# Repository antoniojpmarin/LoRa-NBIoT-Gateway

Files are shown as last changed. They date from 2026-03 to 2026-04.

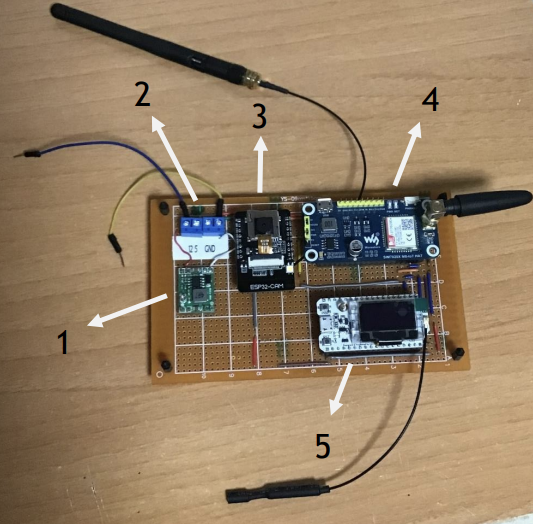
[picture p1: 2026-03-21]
hardware/tfg_image.png

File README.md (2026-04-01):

# Wireless Embedded System for Image Capture, Data Logging and Actuation

**Bachelor's Thesis (TFG)**  
Degree in Industrial Electronics and Automation Engineering  
Universidad Politécnica de Cartagena (UPCT) · July 2024

**Author:** Antonio Joaquín Piñera Marín

---

## Overview

Design and implementation of a low-power wireless embedded system for IoT environments. The system integrates a **LoRa Gateway with NB-IoT connectivity** and an **image capture node**, capable of collecting sensor data, transmitting it over LoRa, pushing it to a cloud IoT platform, and storing images remotely. The project was validated in a real outdoor deployment.

---

## System Architecture

```
[LoRa sensor node]
        │  LoRa (radio)
        ▼
[Gateway — Heltec WiFi LoRa32 (V2)]
   ├── NB-IoT (SIM7020-E) ──────► Thingspeak (sensor data)
   └── [ESP32-CAM] ─── WiFi ───► Firebase Storage (images)
```

The system operates autonomously powered by a solar panel and lead-acid battery.

---

## Hardware

[Perfboard Prototype](https://github.com/antoniojpmarin/LoRa-NBIoT-Gateway/blob/main/hardware/tfg_image.png)

| Component | Role | Number in Image |
|---|---|:---:|
| Heltec WiFi LoRa32 (V2) | Main MCU + LoRa radio + OLED display | 5 |
| ESP32-CAM + OV2640 | Image capture and upload (up to 2 MP) | 3 |
| SIM7020-E | NB-IoT connectivity (M2M) | 4 |
| Solar panel + Lead-acid battery | Autonomous outdoor power supply | Not in the Image |
| Buck converter MP1584 (DC-DC) | Voltage regulation | 1 |
| Perfboard | Final assembly and soldering | Image |

> **Note:** Number **2** in the image corresponds to the **Power Supply Input** (12 V input → 5 V after the DC‑DC converter, or direct 5 V input).

---

## Software

The firmware is split into two independent modules, both developed in **C/C++ with Arduino IDE 2.0**:

### `camera/`
ESP32-CAM node firmware. Handles:
- OV2640 camera module initialisation and configuration
- Periodic image capture
- Authentication and upload to **Firebase Storage** over WiFi
- Low-power modes (*deep sleep*)

### `gateway/`
Heltec WiFi LoRa32 (V2) Gateway firmware. Handles:
- LoRa frame reception from remote sensor nodes
- Data forwarding to **Thingspeak** via the NB-IoT SIM7020-E module (AT commands over UART)
- System status display on the OLED screen
- Coordination with the ESP32-CAM module

---

## Communication Protocols

- **LoRa / LoRaWAN** — long-range, low-power radio link between nodes and Gateway
- **NB-IoT** — cellular connectivity for cloud data upload (SIM7020-E via AT commands / UART)
- **WiFi** — image transfer from ESP32-CAM to Firebase
- **SPI** — interface with the LoRa radio module
- **I²C** — OLED display on the Heltec board
- **UART** — main MCU ↔ SIM7020-E communication

---

## Cloud Platforms

- **[Thingspeak](https://thingspeak.com)** — time-series storage and visualisation of sensor data
- **[Firebase Storage](https://firebase.google.com)** — image storage with authentication and real-time access

---

## Dependencies

Install the following libraries via Arduino IDE Library Manager before compiling:

| Library | Author | Used in |
|---|---|---|
| `LoRa` | Sandeep Mistry | `gateway/` |
| `Firebase ESP Client` | Mobizt | `camera/` |
| `LittleFS` | lorol | `camera/` |
| `esp_camera` | Espressif (built-in) | `camera/` |
| `HardwareSerial` | Espressif (built-in) | `gateway/` |

Board support: install **ESP32 by Espressif Systems** via Arduino IDE Boards Manager.

---

## Results

- Functional LoRa transmission between node and Gateway in an outdoor environment
- Image capture at up to **2 megapixels** with clear visual quality
- Sensor data available on Thingspeak in near real-time after reception
- Images stored on Firebase immediately after capture
- System validated in a real-world deployment (outdoor garden)

---

## Repository Structure

```
├── camera/           # ESP32-CAM firmware (C/C++)
├── gateway/          # LoRa + NB-IoT Gateway firmware (C/C++)
├── hardware/         # KiCad Schematics (MCU, power supply, Buck converter, SIM7020-E, CAM)
└── README.md
```

---

## Tech Stack

**MCU:** ESP32 ( Heltec WiFi LoRa32 V2, ESP32-CAM)  
**Protocols:** LoRa, NB-IoT, WiFi, SPI, I²C, UART  
**Cloud:** [Firebase](https://firebase.google.com/), [Thingspeak](https://thingspeak.mathworks.com/)  
**Languages:** C / C++  
**IDE:** Arduino IDE 2.0
**Schematics:** KiCad

---

## Future Work

- PCB design to reduce footprint, improve robustness and power efficiency
- Computer vision integration (intrusion detection, facial recognition)
- Mobile application development connected to Firebase
- End-to-end data encryption for improved security
- Unification of all communications into a single radio module (WiFi or M2M)

---

## License

Academic project — UPCT 2024. All rights reserved by the author.

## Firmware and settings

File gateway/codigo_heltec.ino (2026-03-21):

#include <SPI.h>
#include <LoRa.h>
#include <HardwareSerial.h>

String receivedData = "";

// Circular buffer size
const int tam_cir_buffer = 15;

// Pins
const int pwrsim7020 = 13;              // Power control pin for SIM7020E
const int pin_cam_signal_sleep = 36;    // Interrupt pin: CAM notifies it entered deep sleep
const int pin_pedir_foto = 23;          // Pin to wake the ESP32-CAM and request a picture

// States
bool flag_data = false;                 // True when a LoRa message has been received
bool cam_sleep = false;                 // True when CAM triggers sleep interrupt

// Deep sleep timing for the camera
long sleep_time = 1000 * 60 * 60;       // 1 hour
long t_inicio_sleep = 0;                // Timestamp of last wake-up

// Circular buffer to store last received values
int circularBuffer[tam_cir_buffer];
int pos_buffer = 0;

// Hardware serial for SIM7020E (UART2)
HardwareSerial sim7020(2);

// SIM7020E UART pins
#define SIM7020_RX_PIN 16
#define SIM7020_TX_PIN 17

// LoRa transceiver pins (SX1276)
#define SCK 5
#define MISO 19
#define MOSI 27
#define SS 18
#define RST 14
#define DIO0 26

void setup(){
  delay(1000);

  Serial.begin(115200);  
  sim7020.begin(115200, SERIAL_8N1, SIM7020_RX_PIN, SIM7020_TX_PIN); // Start SIM7020 UART

  // Configure pins
  pinMode(pwrsim7020, OUTPUT);
  pinMode(pin_pedir_foto, OUTPUT);
  pinMode(pin_cam_signal_sleep, INPUT);

  // Interrupt: CAM notifies when it enters deep sleep
  attachInterrupt(digitalPinToInterrupt(pin_cam_signal_sleep), cam_a_sleep, RISING);

  // Initialize SPI for LoRa
  SPI.begin(SCK, MISO, MOSI, SS);
  LoRa.setPins(SS, RST, DIO0);

  // Start LoRa at 868 MHz
  if (!LoRa.begin(868E6)) {
    Serial.println("Starting LoRa failed!");
    while (1);
  }
  Serial.println("LoRa system Initializing OK!");

  // Initialize circular buffer with -1 (invalid value)
  for (int i = 0; i < tam_cir_buffer; ++i) {
    circularBuffer[i] = -1;
  }

  // Set LoRa to receive mode
  Serial.println("Setting LoRa to receive mode");
  LoRa.onReceive(onReceive);
  LoRa.receive();
}

void loop(){

  // If a LoRa message was received
  if (flag_data){
    Serial.println("Message received!");
    power_on_sim7020();     // Turn on SIM7020E
    delay(800);
    flag_data = false;
    processReceivedData();  // Convert, store and upload the data
  }

  // Wake the CAM every hour to take a picture
  if (millis() - t_inicio_sleep > sleep_time){
    digitalWrite(pin_pedir_foto, HIGH);   // Wake-up pulse
    delay(350);
    digitalWrite(pin_pedir_foto, LOW);
    Serial.println("Waking up the CAM to take a picture!");
    t_inicio_sleep = millis();
  }

  // If CAM triggered sleep interrupt
  if (cam_sleep){
    Serial.println("The CAM has gone to sleep!");
    cam_sleep = false;
  }
}

/*
****************************************************************************************************************************************
  FUNCTION: Upload data to ThingSpeak using SIM7020E HTTP commands
****************************************************************************************************************************************
*/

void upload_data_thingspeak(int dato_){
  sendATCommand("AT");  // Basic check
  sendATCommand("AT+CHTTPCREATE=\"http://api.thingspeak.com/update.json\""); // Create HTTP session
  sendATCommand("AT+CHTTPCON=0"); // Connect session

  String dato_hex = int2hex(dato_);  // Convert number to ASCII HEX
  Serial.println("Received number in hex: " + dato_hex);

  // Send JSON payload encoded in HEX
  sendATCommand("AT+CHTTPSEND=0,1,\"/\",436f6e6e656374696f6e3a204b6565702d416c6976650a557365722d4167656e743a2053494d434f4d5f4d4f44554c450d0a,\"application/json\",7B226170695F6B6579223A222A222C226669656C6431223A"+ dato_hex +"7d");

  sendATCommand("AT+CHTTPDISCON=0");  // Disconnect
  sendATCommand("AT+CHTTPDESTROY=0"); // Destroy session
}

/*
****************************************************************************************************************************************
  FUNCTION: Update circular buffer index
****************************************************************************************************************************************
*/

void actualizar_pos_cir_buffer(){
  pos_buffer++;
  if (pos_buffer >= tam_cir_buffer)
    pos_buffer = 0;
}

/*
****************************************************************************************************************************************
  CALLBACK: Executed when a LoRa packet is received
****************************************************************************************************************************************
*/

void onReceive(int packetSize) {
  receivedData = "";

  // Read all bytes from LoRa buffer
  while (LoRa.available()) {
    receivedData += (char)LoRa.read();
  }

  flag_data = true;  // Notify main loop
}

/*
****************************************************************************************************************************************
  FUNCTION: Process received LoRa data
****************************************************************************************************************************************
*/

void processReceivedData(){
  int dato_int;
  String myString = "";

  // Copy received string
  for (char c : receivedData) {
    myString += c;
  }

  Serial.println("Received number: " + myString);

  // Convert to integer
  dato_int = myString.toInt();
  myString = "";

  // Store in circular buffer
  circularBuffer[pos_buffer] = dato_int;

  // Upload to ThingSpeak
  upload_data_thingspeak(dato_int);
  
  actualizar_pos_cir_buffer();  // Move buffer index
  power_off_sim7020();          // Turn off SIM7020E to save power
}

/*
****************************************************************************************************************************************
  FUNCTION: Send AT command to SIM7020E and wait for "OK"
****************************************************************************************************************************************
*/

void sendATCommand(String command) {
  delay(10);
  sim7020.println(command);  // Send command to SIM7020E

  int t = millis();
  int t_max = 10000;
  String response = "";

  // Wait for response or timeout
  while (millis() - t < t_max){
    delay(20);
    
    if (sim7020.available()) {
      char c = sim7020.read();
      response += c;
      delay(10);
    }

    if (response.indexOf("OK") != -1) {
      break;  // Stop when OK is received
    }
  }

  Serial.println(response);  // Print module response
}

/*
****************************************************************************************************************************************
  INTERRUPT: Called when CAM enters deep sleep
****************************************************************************************************************************************
*/

void cam_a_sleep(){
  cam_sleep = true;
  t_inicio_sleep = millis();  // Reset sleep timer
}

/*
****************************************************************************************************************************************
  FUNCTION: Power ON SIM7020E using pulse sequence
****************************************************************************************************************************************
*/

void power_on_sim7020(){
  digitalWrite(pwrsim7020, LOW);
  delay(100);
  digitalWrite(pwrsim7020, HIGH);
  Serial.println("Powering on SIM7020");
  delay(500);
  digitalWrite(pwrsim7020, LOW);
  delay(1000);
}

/*
****************************************************************************************************************************************
  FUNCTION: Power OFF SIM7020E using pulse sequence
****************************************************************************************************************************************
*/

void power_off_sim7020(){
  digitalWrite(pwrsim7020, LOW);
  delay(100);
  digitalWrite(pwrsim7020, HIGH);
  Serial.println("Powering off SIM7020");
  delay(1000);
  digitalWrite(pwrsim7020, LOW);
}

/*
****************************************************************************************************************************************
  FUNCTION: Convert integer to ASCII HEX for ThingSpeak
****************************************************************************************************************************************
*/

String int2hex(int n){
  String str = String(n);
  String str_valido = ""; // Must start with 3 (ASCII hex prefix)

  for (int i = 0; i < str.length(); i++) {
    if (str.charAt(i) == '.') {
      str_valido += "2e";  // ASCII hex for '.'
    } else {
      str_valido += 3;     // Prefix for ASCII hex digits
      str_valido += str.charAt(i);
    }
  }

  return str_valido;
}

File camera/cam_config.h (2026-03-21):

// OV2640 camera module pins (CAMERA_MODEL_AI_THINKER)
#define PWDN_GPIO_NUM     32
#define RESET_GPIO_NUM    -1
#define XCLK_GPIO_NUM      0
#define SIOD_GPIO_NUM     26
#define SIOC_GPIO_NUM     27
#define Y9_GPIO_NUM       35
#define Y8_GPIO_NUM       34
#define Y7_GPIO_NUM       39
#define Y6_GPIO_NUM       36
#define Y5_GPIO_NUM       21
#define Y4_GPIO_NUM       19
#define Y3_GPIO_NUM       18
#define Y2_GPIO_NUM        5
#define VSYNC_GPIO_NUM    25
#define HREF_GPIO_NUM     23
#define PCLK_GPIO_NUM     22


void initCamera(){
 // OV2640 camera module
  camera_config_t config;
  config.ledc_channel = LEDC_CHANNEL_0;
  config.ledc_timer = LEDC_TIMER_0;
  config.pin_d0 = Y2_GPIO_NUM;
  config.pin_d1 = Y3_GPIO_NUM;
  config.pin_d2 = Y4_GPIO_NUM;
  config.pin_d3 = Y5_GPIO_NUM;
  config.pin_d4 = Y6_GPIO_NUM;
  config.pin_d5 = Y7_GPIO_NUM;
  config.pin_d6 = Y8_GPIO_NUM;
  config.pin_d7 = Y9_GPIO_NUM;
  config.pin_xclk = XCLK_GPIO_NUM;
  config.pin_pclk = PCLK_GPIO_NUM;
  config.pin_vsync = VSYNC_GPIO_NUM;
  config.pin_href = HREF_GPIO_NUM;
  config.pin_sscb_sda = SIOD_GPIO_NUM;
  config.pin_sscb_scl = SIOC_GPIO_NUM;
  config.pin_pwdn = PWDN_GPIO_NUM;
  config.pin_reset = RESET_GPIO_NUM;
  config.xclk_freq_hz = 20000000;
  config.pixel_format = PIXFORMAT_JPEG;
  config.grab_mode = CAMERA_GRAB_LATEST;

  if (psramFound()) {
    config.frame_size = FRAMESIZE_UXGA;
    config.jpeg_quality = 10;
    config.fb_count = 1;
  } else {
    config.frame_size = FRAMESIZE_SVGA;
    config.jpeg_quality = 12;
    config.fb_count = 1;
  }
  // Camera init
  esp_err_t err = esp_camera_init(&config);
  if (err != ESP_OK) {
    Serial.printf("Camera init failed with error 0x%x", err);
    ESP.restart();
  } 
}

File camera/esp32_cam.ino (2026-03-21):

#include "WiFi.h"
#include "esp_camera.h"
#include "soc/soc.h"           // Disable brownout problems
#include "soc/rtc_cntl_reg.h"  // Disable brownout problems
#include "driver/rtc_io.h"
#include <LittleFS.h>
#include <Firebase_ESP_Client.h>
#include <addons/TokenHelper.h>
#include "esp_sleep.h"

#include "cam_config.h"
#include "firebase_datos.h"

const char* ssid = "******";
const char* password = "*******";

int intentos_subir_foto = 0, ledpin = 4, go_sleep = 12;
String filePath = "";
bool foto_subida = false;
bool debug = true;

void setup() {
  delay(500);

  if (debug){
    Serial.begin(115200);
  }

  pinMode(ledpin, OUTPUT);
  pinMode(go_sleep, OUTPUT);

  Serial.println("Hola");

  esp_sleep_enable_ext0_wakeup(GPIO_NUM_13, 1);

  if(!LittleFS.begin()){
    Serial.println("LittleFS Mount Failed");
  }

  LittleFS.format(); // Limpio LittleFS

  WRITE_PERI_REG(RTC_CNTL_BROWN_OUT_REG, 0);
  initCamera();
}

void loop(){
  // Toma una foto y guárdala
  capturePhotoSaveLittleFS();
  Serial.println(String("Nombre del archivo: ") + String("/data") + filePath);

  int n = 0;
  WiFi.begin(ssid, password);
  while (WiFi.status() != WL_CONNECTED && n < 15){
    n++;
    Serial.print("*");
    delay(1000);
  }
  Serial.println("");

  if (WiFi.status() == WL_CONNECTED){
    firebase();
  }

  while (intentos_subir_foto < 3 && !foto_subida && WiFi.status() == WL_CONNECTED){
    if (Firebase.Storage.upload(&fbdo, STORAGE_BUCKET_ID, filePath, mem_storage_type_flash, "/data"+filePath, "image/jpeg")){
      Serial.println("Foto Subida a Firebase!");
      foto_subida = true;
    }
    else intentos_subir_foto++;
  }

  if (intentos_subir_foto == 3 && !foto_subida){
    Serial.println("No se ha podido subir la foto!!!!");
  }

  Serial.println("Vamos al modo sleep!");

  digitalWrite(go_sleep, HIGH);
  delay(400);
  digitalWrite(go_sleep, LOW);

  digitalWrite(ledpin, HIGH);
  delay(300);
  digitalWrite(ledpin, LOW);
  delay(200);
  digitalWrite(ledpin, HIGH);
  delay(300);
  digitalWrite(ledpin, LOW);
  delay(200);
  digitalWrite(ledpin, HIGH);
  delay(300);
  digitalWrite(ledpin, LOW);
  delay(200);

  esp_deep_sleep_start();
}

//Firebase
void firebase(){
  // Api Key
  configF.api_key = API_KEY;

  // Credenciales de incio de sesión
  auth.user.email = USER_EMAIL;
  auth.user.password = USER_PASSWORD;

  // Función callback para el token de generación
  //configF.token_status_callback = tokenStatusCallback; //see addons/TokenHelper.h

  Firebase.begin(&configF, &auth);
  //Firebase.reconnectWiFi(true);
  Serial.println("Firebase configurado!");
}

// Capture Photo and Save it to LittleFS
void capturePhotoSaveLittleFS( void ) {
  // Descartar primeras imágenes debido a la mala calidad
  camera_fb_t *fb = NULL;
  // Omitir los primeros 3 fotogramas (aumentar o disminuir según sea necesario).

  for (int i = 0; i < 4; i++) {
    fb = esp_camera_fb_get();
    esp_camera_fb_return(fb);
    fb = NULL;
  }
  
  // Tomar una nueva foto
  fb = NULL;  
  digitalWrite(ledpin, HIGH);
  fb = esp_camera_fb_get();
  delay(300);
  digitalWrite(ledpin, LOW);
  if(!fb) {
    Serial.println("Fallo al capturar la imagen");
    delay(1000);
  }

  else Serial.println("Imagen capturada correctamente!");

  // Antes de crear un nuevo archivo, compruebo si existe ya uno con el path: /foto1.jpeg . Si existe entonces /foto +1 .jpeg, y vuelvo a comprobar, y así
  // Con el LittleFS.open() se crea el archivo nuevo, en la ruta que especifique, en el modo que desee (write / read)
  // Construct the file path for the photo
  filePath = generateRandomFilepath();
  Serial.println(filePath);

  delay(40);

  // Once the name is assigned, we'll create a LittleFS file where saving it
  File file_littlefs = LittleFS.open(filePath, "w");

  // Insertar los datos en el archivo de la foto
  if (!file_littlefs) {
    Serial.println("Error al abrir el archivo en modo escritura");
  }
  else {
    file_littlefs.write(fb->buf, fb->len); // Carga útil (imagen), longitud de la carga útil
    Serial.println("Imagen guardada en LittleFS!");
  }

  // Cerrar el archivo
  file_littlefs.close();

  esp_camera_fb_return(fb);
}

String generateRandomFilepath() {
    String filepath_ = "/foto_";
    filepath_ += String(random(1000));  // Añade un número aleatorio de 0 a 999
    filepath_ += "_";
    filepath_ += String(millis());  // Añade el tiempo actual en milisegundos
    filepath_ += ".jpeg";  // Extensión de archivo para una foto JPEG
    return filepath_;
}
